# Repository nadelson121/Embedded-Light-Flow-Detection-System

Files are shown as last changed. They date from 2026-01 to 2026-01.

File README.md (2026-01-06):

Arduino Light-Tracking System

An embedded system built with an Arduino Uno that detects the direction of maximum light intensity and automatically rotates a servo motor to align with it. The system uses a photoresistor mounted on a rotating arm to scan light levels and dynamically adjust positioning.

Overview

The servo performs a 180° sweep to collect real-time light intensity data. The system determines the angle with the highest light level and repositions the arm accordingly. Users can modify scan delays and sensitivity thresholds at runtime via serial input, and reset the system using a push button.

Features

180° servo sweep for light detection

Automatic alignment to strongest light source

Runtime configuration via serial communication

User-defined sensitivity and scan delay

Push-button reset support

Real-time serial logging for debugging

Hardware Used

Arduino Uno

Servo motor

Photoresistor (LDR)

Push button

Resistors

Breadboard and jumper wires

Software

Arduino IDE

C/C++ (Arduino framework)

Applications

Solar tracking systems

Light-following robotics

Embedded sensing and control projects

How It Works

Servo sweeps from 0° to 180° collecting light readings

Maximum light intensity and corresponding angle are calculated

Servo rotates to the optimal angle

System adapts to user-defined sensitivity and environmental changes

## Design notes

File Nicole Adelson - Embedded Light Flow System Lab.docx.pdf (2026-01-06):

## INTRODUCTION TO EMBEDDED SYSTEMS AND IOTS

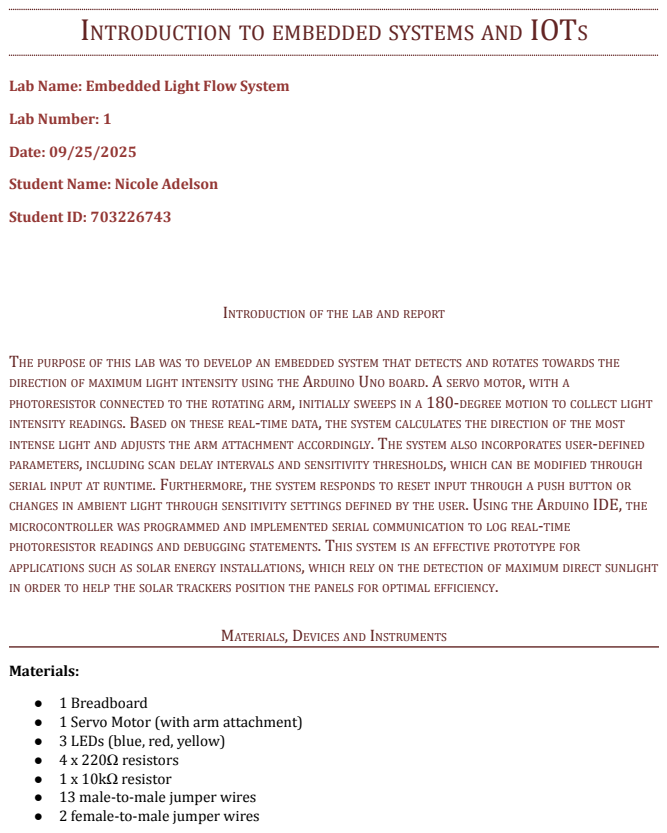
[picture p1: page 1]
Lab Number: 1; Date: 09/25/2025; Student ID: 703226743; Materials:

Lab Name: Embedded Light Flow System

Student Name: Nicole Adelson

INTRODUCTION OF THE LAB AND REPORT

THE PURPOSE OF THIS LAB WAS TO DEVELOP AN EMBEDDED SYSTEM THAT DETECTS AND ROTATES TOWARDS THE
DIRECTION OF MAXIMUM LIGHT INTENSITY USING THE ARDUINO UNO BOARD. A SERVO MOTOR, WITH A
PHOTORESISTOR CONNECTED TO THE ROTATING ARM, INITIALLY SWEEPS IN A 180-DEGREE MOTION TO COLLECT LIGHT
INTENSITY READINGS. BASED ON THESE REAL-TIME DATA, THE SYSTEM CALCULATES THE DIRECTION OF THE MOST
INTENSE LIGHT AND ADJUSTS THE ARM ATTACHMENT ACCORDINGLY. THE SYSTEM ALSO INCORPORATES USER-DEFINED
PARAMETERS, INCLUDING SCAN DELAY INTERVALS AND SENSITIVITY THRESHOLDS, WHICH CAN BE MODIFIED THROUGH
SERIAL INPUT AT RUNTIME. FURTHERMORE, THE SYSTEM RESPONDS TO RESET INPUT THROUGH A PUSH BUTTON OR
CHANGES IN AMBIENT LIGHT THROUGH SENSITIVITY SETTINGS DEFINED BY THE USER. USING THE ARDUINO IDE, THE
MICROCONTROLLER WAS PROGRAMMED AND IMPLEMENTED SERIAL COMMUNICATION TO LOG REAL-TIME
PHOTORESISTOR READINGS AND DEBUGGING STATEMENTS. THIS SYSTEM IS AN EFFECTIVE PROTOTYPE FOR
APPLICATIONS SUCH AS SOLAR ENERGY INSTALLATIONS, WHICH RELY ON THE DETECTION OF MAXIMUM DIRECT SUNLIGHT
IN ORDER TO HELP THE SOLAR TRACKERS POSITION THE PANELS FOR OPTIMAL EFFICIENCY.

MATERIALS, DEVICES AND INSTRUMENTS

● 1 Breadboard
● 1 Servo Motor (with arm attachment)
● 3 LEDs (blue, red, yellow)
● 4 x 220Ω resistors
● 1 x 10kΩ resistor
● 13 male-to-male jumper wires
● 2 female-to-male jumper wires

Devices:

- Arduino UNO
- HP Laptop with Arduino IDE

SCHEMATICS

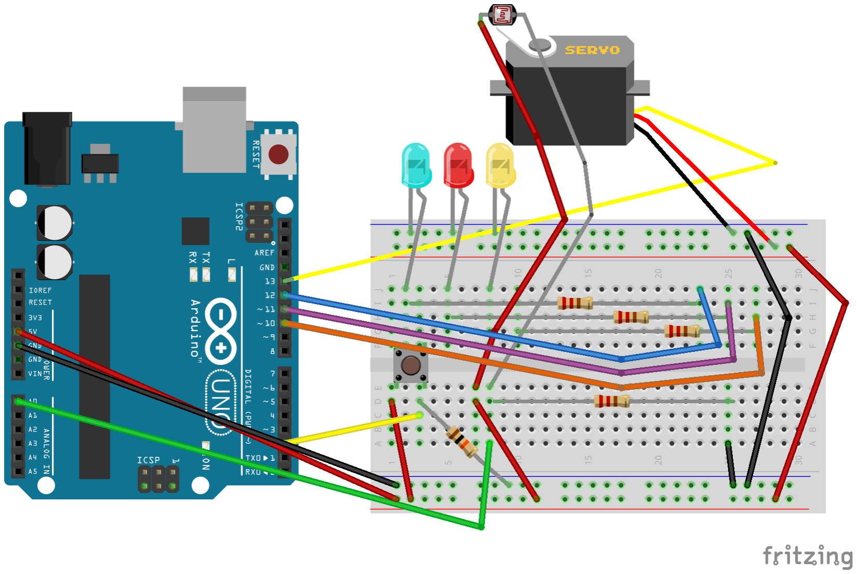
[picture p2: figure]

LAB METHODS AND PROCEDURE

This light-tracking system was implemented on a breadboard using an Arduino Uno microcontroller. The servo motor was connected to PWM pin 9, the push-bottom for rescans connected to PWM pin 2, and the three LEDs connected to pins 4 (blue), 5 (yellow), and 6(red) with 220Ω resistors. The photoresistor was mounted on the servo arm using electrical tape to face outward toward the light source.A voltage divider circuit was developed by connecting one leg to the 5V pin the other leg to ground through a 10kΩ resistor, and connecting the junction to analog pin A0.. The push-button was connected to the 10kΩ pull-up resistor, and events were tracked through an external interrupt on pin 2. Automatic scanning was maintained in the main loop using the millis() function for timing. Additionally, a boolean flag was set inside the ISR to signal a rescan, which allowed the main loop to control the servo movements, LED updates, and scanning periods without conflicts. Serial communication was also initialized to display debugging information and log photoresistor readings.

During each scan, the servo sweeps from 0 degrees to 180 degrees in 5-degree increments, pausing briefly at each step to allow the photoresistor readings to stabilize. At each step, multiple photoresistor readings are averaged to minimize noise. The system continuously records the values from the photoresistor to determine the angle with the maximum light intensity. Once identified, the servo rotates to this position, aligning the arm with the brightest light source. During this process, the yellow LED turns on to indicate active scanning, the blue LED turns on when the system is ready and after a full scan, and the red LED illuminates if there is an interrupt either due to the time elapsed reaching the user-defined interval or the change in light intensity exceeding the user-defined sensitivity threshold.

TROUBLE IN THE LAB AND HOW DID YOU SOLVE IT

There were various challenges in hardware and software integration for the light-tracking system. One key hardware issue was guaranteeing that the photoresistor remained stable during operation, as movement would lead to inconsistent readings. This was resolved by securing it to the servo arm with electrical tape. The servo arm itself also presented challenges, initially failing to rotate consistently due to conflicting TimerOne interrupts. This functionality was temporarily removed to restore proper motion and address any coinciding issues. Additionally, the connection of the female-to-male jumper wires to the photoresistor were prone to disconnection, and the red LED failed to illuminate, both of which were addressed by carefully securing the components and physical adjustments, such as electrical tape around the jumper wire connection.

From the software perspective, accurately tracking the light source required more than one reading per servo angle and averaging the values to reduce noise, while also ignoring substantial jumps in intensity to ensure stability. The manual rescans by pressing the pushbutton initially did not register, which required proper debouncing of 200ms alongside the rescan flag in the ISR. Each scan was set to start at 0 degrees upon setting the rescan flag and all of the readings from the previous sweep were wiped in order to demonstrate a sufficient reset of the system. These hardware and software adjustments allowed the system to achieve consistent, responsive operation.

RESULTS AND CONCLUSION

The system was able to successfully track the brightest light source after sweep sessions. The servo accurately rotated towards the maximum photoresistor reading, and rescans were effectively instantiated by the timer every 5 seconds and manually by pressing the push-button. The LED feedback worked as intended, with the yellow LED illuminated during the scanning period, the blue LED turned on when the system was ready and when there was a successful full scan, and the red LED displaying that the system had exceeded its set runtime or detected a light interval change that exceeded the defined sensitivity threshold. The serial outputs were able to confirm the maximum intensity angle and the corresponding photoresistor values, demonstrating reliable analysis among several tests. The system was able to respond consistently, with varying ambient light levels.

The successful design and implementation of this light-tracking system shows the effective application of sensor input, servo control, user-defined parameters, and interrupts in an applicable Arduino-based project. The use of event-driven interrupts for rescans based on light change and push-button input enabled flexibility between automatic and manual scans, while the dynamic LED feedback displayed the system states easily for users. Despite its simplicity, the system adapts crucial principles in embedded design, including minimal interrupts, clear feedback, and reliable infrastructure. This project demonstrates the use of microcontrollers for real-time environmental tracking, and provides a sturdy foundation for further applications.

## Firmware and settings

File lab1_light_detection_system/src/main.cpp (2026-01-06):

#include <Arduino.h>
#include <Servo.h>

/* Pin initialization */
const int servoPin   = 9;      // PWM pin for servo
const int rescanPin  = 2;      // pushbutton for manual rescan
const int blueLED    = 12;     // Blue LED to indicate that the system is ready and if the scan finished successfully
const int yellowLED  = 10;     // Yellow LED to indicate that the system is scanning
const int redLED     = 7;      // Red LED to indicate that there is a rescan about to be initiated from the pushbutton trigger or change in light sensitivity at the source's angle location

/* Servo object */
Servo myServo;

/* Rescan flags */
volatile bool rescanRequested = false;
volatile unsigned long lastInterruptTime = 0; // debounce for button

/* Automatic scan timing */
unsigned long lastScan = 0;     // stores when the last scan ended
unsigned long scanInterval = 5000; // default = 5 seconds

/* Light sensitivity */
int lightThreshold = 80;         // user-adjustable sensitivity threshold

/* Post-scan monitoring */
int originalLightValue = 0;      // max intensity from last scan
int bestAngle = 0;               // angle with max intensity from last scan
unsigned long lastRecheck = 0;   // stores when the last recheck ended
const unsigned long recheckInterval = 2000; // recheck interval in ms

/* ISR for pushbutton */
void requestRescan() {
    unsigned long currentTime = millis();
    if (currentTime - lastInterruptTime > 200) { // debounce
        rescanRequested = true;
        lastInterruptTime = currentTime;
        Serial.println("Button pressed! Interrupt detected.");
    }
}

/* Read light value with averaging to prevent noise */
int readLight(int samples = 5) {
    long total = 0;
    for (int i = 0; i < samples; i++) {
        total += analogRead(A0);
        delay(5);
    }
    return total / samples;
}

/* Light scanning function */
void scanLight() {
    digitalWrite(blueLED, LOW);
    digitalWrite(yellowLED, HIGH); // LED indicator for scan-in-progress
    digitalWrite(redLED, LOW);
    Serial.println("Scanning...");

    int selected_angle = 0;
    int selected_intensity = -1;

    for (int angle = 0; angle <= 180; angle += 5) {
        digitalWrite(redLED, LOW);
        digitalWrite(yellowLED, HIGH);
        digitalWrite(blueLED, LOW);  
        // Check for pushbutton rescan
        if (rescanRequested) {
            Serial.println("Scan interrupted! Restarting sweep.");
            digitalWrite(redLED, HIGH); // LED indicator for rescan
            digitalWrite(yellowLED, LOW);
            digitalWrite(blueLED, LOW);
            rescanRequested = false;
            myServo.write(0);
            delay(300); // delay to stabilize Servo
            angle = -5; // restart sweep
            selected_angle = 0; // reset angle of max intensity
            selected_intensity = -1; // reset value of max intensity
            continue; // proceed with the loop for next scan
        }
      
        myServo.write(angle); // set the angle of Servo as it sweeps
        delay(200);

        int lightValue = readLight(); // read light intensity
        Serial.print("Angle: ");
        Serial.print(angle);
        Serial.print(" - Avg Intensity: ");
        Serial.println(lightValue);

        if (lightValue > selected_intensity) { 
            selected_intensity = lightValue; // update maximum intensity with the largest intensity in the sweep
            selected_angle = angle; // update the angle with the location of the strongest source
        }
    }

    myServo.write(selected_angle); // move the servo to the angle with maximum intensity
    bestAngle = selected_angle; // update all-time best angle in terms of intensity for new scan
    originalLightValue = selected_intensity; // update all-time maximum intensity

    Serial.print("Max intensity at angle: ");
    Serial.println(selected_angle);

    digitalWrite(blueLED, HIGH); // LED indicator for successful scan
    digitalWrite(redLED, LOW);

    digitalWrite(yellowLED, LOW);
    Serial.println("Scan done!");
    delay(1000);
    lastScan = millis(); // keeping track of when scan finished
}

/* Setup */
void setup() {
    Serial.begin(9600);
    /* Serial setup */
    while (!Serial) { ; } // waits for scan interval or sensitivity threshold from user; eventually, proceeds with defaults
    Serial.println("System ready. Enter scan interval in ms (default = 5000) and light threshold (default = 80).");

    /* Servo setup */
    myServo.attach(servoPin);


    /* LED setup */
    pinMode(blueLED, OUTPUT);
    pinMode(yellowLED, OUTPUT);
    pinMode(redLED, OUTPUT);

    pinMode(rescanPin, INPUT_PULLUP);
    attachInterrupt(digitalPinToInterrupt(rescanPin), requestRescan, FALLING);


    /* Initialize LEDs */
    digitalWrite(blueLED, HIGH);
    digitalWrite(yellowLED, LOW);
    digitalWrite(redLED, LOW);

    /* Initializes time variables */
    lastScan = millis();
    lastRecheck = millis();
}

/* Main loop */
void loop() {
    // --- Handle user input for scan interval or sensitivity ---
    if (Serial.available() > 0) {
        String input = Serial.readStringUntil('\n');
        input.trim(); // removes trailing white space
        if (input.length() > 0) {
            if (input.charAt(0) == 'S' || input.charAt(0) == 's') { // check if there is user input for sensitivity
                int newSens = input.substring(1).toInt();
                if (newSens > 0) {
                    lightThreshold = newSens; // updates sensitivity threshold to user-defined value
                    Serial.print("Sensitivity updated to: ");
                    Serial.println(lightThreshold);
                }
            } else { // if there is input but nothing to indicate that the user inputted a sensitivity value, assume it is related to scan interval
                unsigned long newInterval = input.toInt();
                if (newInterval > 0) {
                    scanInterval = newInterval; // updates scan interval to user-defined value (in ms)
                    Serial.print("Scan interval updated to: ");
                    Serial.print(scanInterval);
                    Serial.println(" ms");
                }
            }
        }
    }

    // --- Trigger scan if button pressed or automatic interval elapsed ---
    if (rescanRequested || (millis() - lastScan >= scanInterval)) {
        bool manualTrigger = rescanRequested;
        rescanRequested = false; // clear before scanning

        if (manualTrigger) { // checks for trigger from light sensitivity change
            Serial.println(">>> Manual/light-triggered scan starting...");
        } else {
            Serial.println(">>> Automatic scan triggered...");
        }

        //lastScan = millis();
        digitalWrite(blueLED, HIGH); // LED indicator that system is ready
        digitalWrite(yellowLED, LOW);
        digitalWrite(redLED, LOW);

        delay(1500); // stabilizing LEDs
        scanLight(); // starts the scan
    }

    // --- Post-scan monitoring at best angle ---
    if (!rescanRequested && (millis() - lastRecheck >= recheckInterval)) {
        lastRecheck = millis();

        myServo.write(bestAngle); // ove servo to last position of maximum light intensity
        delay(100);

        int currentLight = readLight(); // gets light reading from current position
        Serial.print("Post-scan light check at angle ");
        Serial.print(bestAngle);
        Serial.print(": ");
        Serial.println(currentLight);

        // If the difference between the current and original light intensity is greater than the defined threshold, new scan is triggered
        Serial.println(">>> Light changed significantly! Triggering new scan.");
        if (abs(currentLight - originalLightValue) >= lightThreshold) { 
            rescanRequested = true;
        }
    }
}
